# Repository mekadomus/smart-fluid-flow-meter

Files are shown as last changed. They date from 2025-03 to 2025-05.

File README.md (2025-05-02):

# Smart Fluid Flow Meter



Hardware and software for a system that monitors flow of fluids (most likely water) and reports it to a back-end that can emit alerts based on configured preferences.

- [case](/case/) - 3d model of the PCB case
- [firmware](/firmware/) - The firmware code that takes care of reading the sensor and posting measurements to the back-end
- [electronics](/electronics/) - Electronic circuit schematic and pcb

## User documentation

- [English](/docs/en/)
- [Español](/docs/es/)

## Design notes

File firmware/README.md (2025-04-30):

# ESP32

The firmware for `smart-fluid-flow-meter`.

Reads measurements from [YF-S201](http://www.mantech.co.za/datasheets/products/yf-s201_sea.pdf) and publishes them to the back-end.

## Configure

A few settings can be configured to modify the resulting executable. To set these configurations you need to create the configuration file:

```
cp sdkconfig.sample src/sdkconfig.defaults
```

And then update `src/sdkconfig.defaults` as desired

## Update git submodules

```
git submodule update --init --recursive
```

## Compile

To generate a docker image and build the code:

```
make build
```

## Upload to ESP32 dev board

Assumes the device is connected at `/dev/ttyACM0`.

```
make upload
```

## Monitor serial port

Assumes the device is connected at `/dev/ttyACM0`.

```
make serial
```

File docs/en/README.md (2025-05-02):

# User documentation

## LED indicators

- **Yellow** - Device is booting
- **Green, yellow and red** - Device set to factory settings and waiting for configuration (See below for instructions to configure)
- **Green** - Device is configured and behaving correctly
- **Green and yellow** - Device is in the middle of sending a request to the back-end
- **Red** - Last request to back-end failed. This could be because configuration is incorrect, or the configured modem is unreachable
- **None** - This should not happen, it means something is very wrong

## Configuration

When the device is in factory settings (Green, yellow and red LEDs on), the firmware will start an access point named `my-esp32-ssid`. Connect to the access point using the password `APassword`.

Once connected, navigate to the url: `sffm.mekadomus.com`. You should get a screen like the following:

Configure device screen

Fill the data as follows:
- *Wifi Network* - The name of the network the device will connect to
- *Wifi Password* - The password for the given SSID
- *Device key* - The unique identifier for this device. This ID must match the ID of a device created at the backend ([https://console.mekadomus.com](https://console.mekadomus.com))

After submitting the form, you should get the following confirmation screen:

Configuration saved screen

The device will proceed to disable the access point and will start reading measurements from the sensor and sending them to the backend every  `MS_BETWEEN_POSTS`.

## Factory reset

If you need to re-configure the device, press and hold the device button for 5 seconds. After some time the green, yellow and red LEDs should all turn on.

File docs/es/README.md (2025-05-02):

# User documentation

## Indicadores LED

- **Amarillo** - Dispositivo iniciando
- **Verde, amarillo y rojo** - Dispositivo en modo fábrica. Listo para ser configurado (Ver instrucciones abajo para configurar)
- **Verde** - Dispositivo configurado y funcionando correctamente
- **Verde y amarillo** - Dispositivo enviando información a servidores
- **Rojo** - La última petición a los servidores fallo. Esto puede suceder porque el dispositivo está mal configurado o el punto de acceso no está disponible
- **Ninguno** - Esto nunca debería suceder. Significa que algo está funcionando mal

## Configuración

Cuando el dispositivo está en modo fabrica (Indicadores LED verde, amarillo y rojo están encendidos), el dispositivo crea un punto de acceso llamado `my-esp32-ssid`. Conéctate a esa red usando la contraseña `APassword`.

Una vez conectado, visita la dirección `sffm.mekadomus.com`. Verás una página similar a la siguiente:

Configure device screen

Llena los datos:
- *Red* - El nombre de la red al que se conectará el dispositivo
- *Contraseña* - Contraseña de la red seleccionada
- *ID del medidor* - Identificador para este dispositivo. Debe ser igual a un ID creado desde el panel de control: ([https://console.mekadomus.com](https://console.mekadomus.com))

Después de enviar la información recibirás este mensaje:

Configuration saved screen

El dispositivo desactivará el punto de acceso `my-esp32-ssid` y empezará a mandar mediciones a los servidores cada `MS_BETWEEN_POSTS`.

## Modo fábrica

Si necesitar reconfigurar el dispositivo, mantén presionado el botón en el dispositivo por 5 segundos. Los LEDs verde, amarillo y rojo se encenderán de nuevo y el dispositivo estará listo para configurarse.

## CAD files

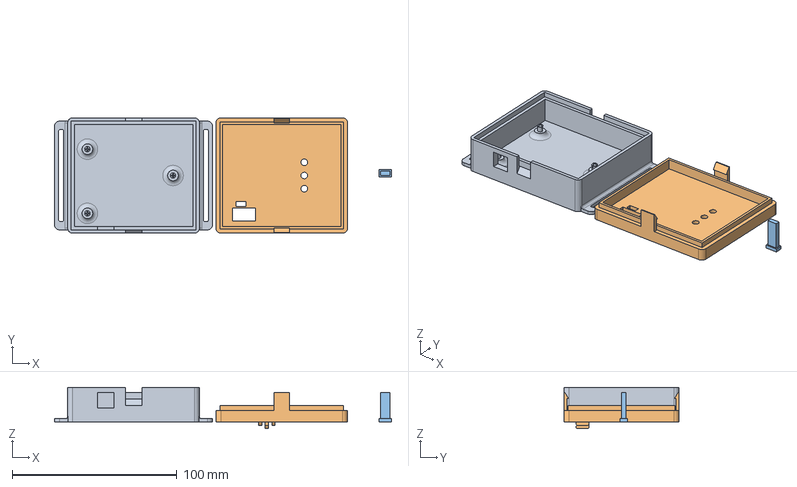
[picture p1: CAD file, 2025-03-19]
case/indoor/case.FCStd
204.7 x 70.0 x 25.0 mm
bottom_b
top_b
button_b

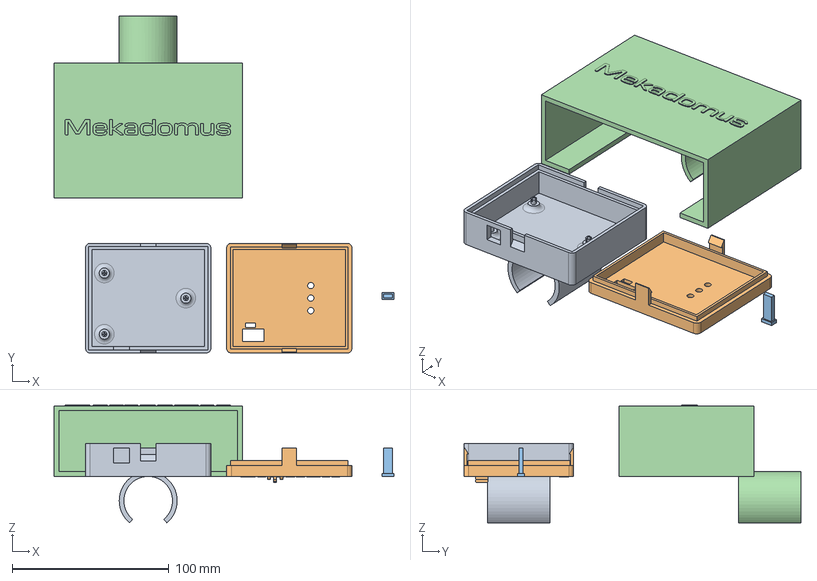
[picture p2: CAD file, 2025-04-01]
case/outdoor/case.FCStd
216.7 x 215.0 x 75.2 mm
bottom_b
top_b
button_b
rain_protector_body

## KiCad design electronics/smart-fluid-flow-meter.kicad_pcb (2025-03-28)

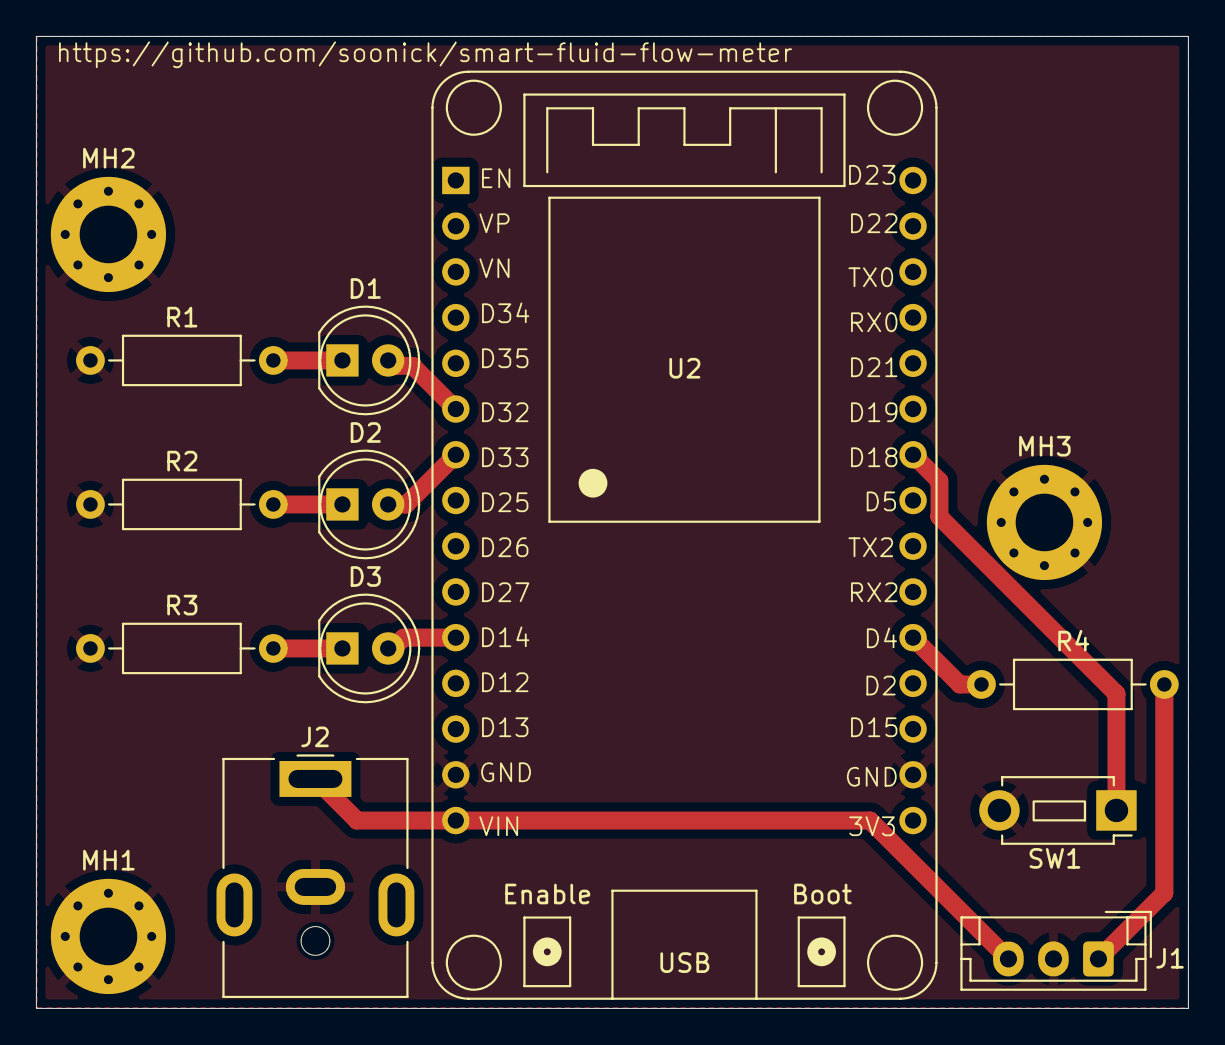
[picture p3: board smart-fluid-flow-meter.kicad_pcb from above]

Board: 2 copper layers, 64.0 x 54.0 mm, 14 parts (0 on the bottom side), 11 nets.

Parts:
D1: Green LED; LED_D5.0mm
D2: Yellow LED; LED_D5.0mm
D3: Red LED; LED_D5.0mm
J1: YF-S201; JST_EH_B3B-EH-A_1x03_P2.50mm_Vertical
J2: Barrel_Jack; BarrelJack_CUI_PJ-063AH_Horizontal
MH1, MH2, MH3: MountingHole_Pad; MountingHole_3.2mm_M3_Pad_Via
R1, R3: 220; R_Axial_DIN0207_L6.3mm_D2.5mm_P10.16mm_Horizontal
R2: 100; R_Axial_DIN0207_L6.3mm_D2.5mm_P10.16mm_Horizontal
R4: 3.3M; R_Axial_DIN0207_L6.3mm_D2.5mm_P10.16mm_Horizontal
SW1: Factory reset button; SW_PUSH_1P1T_6x3.5mm_H4.3_APEM_MJTP1243
U2: ESP32-DevkitV1; esp32_devkit_v1

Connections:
0: J1.2, J2.2, MH1.1, MH2.1, MH3.1, R1.1, R2.1, R3.1, SW1.2, U2.2 (GND), U2.29 (GND)
unnamed: D1.2 (A), U2.21 (D32)
unnamed: D1.1 (K), R1.2
unnamed: D2.2 (A), U2.22 (D33)
unnamed: D2.1 (K), R2.2
unnamed: D3.2 (A), U2.26 (D14)
unnamed: D3.1 (K), R3.2
unnamed: J1.1, R4.2
unnamed: J1.3, J2.1, U2.30 (VIN)
unnamed: R4.1, U2.5 (D4)
unnamed: SW1.1, U2.9 (D18)

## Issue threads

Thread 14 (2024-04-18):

Create network where user can input network credentials

soonick, 2024-04-18:

soonick, 2024-04-19:
Here is basically what we need: https://www.instructables.com/Avoid-Hard-Coding-WiFi-Credentials-on-Your-ESP8266/

soonick, 2024-04-19:
That library doesn't work with Arduino UNO R4 Wifi. This might be useful: https://www.elektroda.com/rtvforum/topic4000214.html

Closed 2024-06-26.

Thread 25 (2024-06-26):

Reset user configuration when a reset button is long pressed

soonick, 2024-06-26:

Closed 2024-07-05.

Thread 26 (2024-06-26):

Show in LEDs the current status of the system

soonick, 2024-06-26:
- AP is on
- Connected to configured network
- Configured but not connected
- Booting
- Resetting

soonick, 2024-07-23:
Connected to configured network: Green
AP mode: Yellow
Error connecting to network: Red
Booting/Resetting: Blinking all LEDs

Closed 2024-11-25.

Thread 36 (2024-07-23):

Wifi posts are super unreliable

soonick, 2024-07-23:

soonick, 2024-08-06:
Since we are moving to ESP32, this might change. I'll re-open if I find the same issue there

Closed 2024-08-06.

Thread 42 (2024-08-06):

[Arduino -> ESP32] Reset wifi credentials functionality

soonick, 2024-08-06:

Closed 2024-11-12.

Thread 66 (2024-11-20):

Investigate if there is a way to use low power mode and wake up from interrupt

soonick, 2024-11-20:

soonick, 2024-11-22:
Won't do as using battery doesn't seem to be an option for now

Closed 2024-11-22.

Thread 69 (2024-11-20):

Battery usage analysis

soonick, 2024-11-20:

soonick, 2024-11-20:
**Current measurements**

- Long sleep - 0.34 mA
- Wifi on. Sending https requests - 1.27 mA
- Access point on - 1.18 mA

My local supplier has these 3.7v LiPo batteries:

- 1000 mAh - 4 USD
- 2000 mAh - 8 USD

Which means, at maximum power consumption, the batteries would last approximately:

- 1000 mAh - 1 month
- 2000 mAh - 2 months

At minimum power consumption, the batteries would last approximately:

- 1000 mAh - 4 months
- 2000 mAh - 8 months

If I only use wifi every few hours, maybe I can get 6 moths for the large battery, but it still seems like too little autonomy. Deep sleep (if even possible) might add a nother couple of months, but 8 months still sounds like too little. I'll stick to a plugged solution for now.

soonick, 2024-11-20:
After some research, my previous measurements might be wrong. After checking the amp meter settings, I can see that with the wifi on and sending data, usage can get up to 160 mA.

This makes the autonomy even worse, so I'm just going to continue with a plugged solution.

Closed 2024-11-20.

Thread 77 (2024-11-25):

PCB improvements

soonick, 2024-11-25:
- Use wider traces
- GND plane / pour

After done, send PCB for review to https://www.reddit.com/r/PrintedCircuitBoard/ making sure to follow https://old.reddit.com/r/PrintedCircuitBoard/wiki/index#wiki_instructions_for_reviews

soonick, 2024-11-28:
Sent for review: https://www.reddit.com/r/PrintedCircuitBoard/comments/1h24an5/review_request_esp32devkitv1_with_water_flow/

Closed 2024-12-02.

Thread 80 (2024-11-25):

HTTPS requests sometimes fails

soonick, 2024-11-25:
It seems to be a recoverable error. This is a log:

```
E (21600716) smart-fluid-flow-meter: Sending request
I (21600756) wifi:wifi driver task: 3ffd4168, prio:23, stack:6656, core=0
I (21600766) wifi:wifi firmware version: ccaebfa
I (21600766) wifi:wifi certification version: v7.0
I (21600766) wifi:config NVS flash: enabled
I (21600776) wifi:config nano formating: disabled
I (21600776) wifi:Init data frame dynamic rx buffer num: 32
I (21600786) wifi:Init static rx mgmt buffer num: 5
I (21600786) wifi:Init management short buffer num: 32
I (21600786) wifi:Init dynamic tx buffer num: 32
I (21600796) wifi:Init static rx buffer size: 1600
I (21600796) wifi:Init static rx buffer num: 10
I (21600806) wifi:Init dynamic rx buffer num: 32
I (21600856) wifi_init: rx ba win: 6
I (21600856) wifi_init: accept mbox: 6
I (21600856) wifi_init: tcpip mbox: 32
I (21600856) wifi_init: udp mbox: 6
I (21600856) wifi_init: tcp mbox: 6
I (21600886) wifi_init: tcp tx win: 5760
I (21600886) wifi_init: tcp rx win: 5760
I (21600886) wifi_init: tcp mss: 1440
I (21600886) wifi_init: WiFi IRAM OP enabled
I (21600886) wifi_init: WiFi RX IRAM OP enabled
I (21600956) wifi:mode : sta (a0:dd:6c:0e:ef:80)
I (21600956) wifi:enable tsf
I (21600966) backend-service: Connecting to Chacmultun-13-2...
W (21600966) wifi:Password length matches WPA2 standards, authmode threshold changes from OPEN to WPA2
W (21600986) event: handler already registered, overwriting
I (21600996) wifi:new:<11,2>, old:<1,0>, ap:<255,255>, sta:<11,2>, prof:1, snd_ch_cfg:0x0
I (21600996) wifi:state: init -> auth (0xb0)
I (21601006) wifi:state: auth -> assoc (0x0)
I (21601016) wifi:state: assoc -> run (0x10)
I (21601036) wifi:connected with Chacmultun-13-2, aid = 3, channel 11, 40D, bssid = 14:cc:20:fd:13:d5
I (21601036) wifi:security: WPA2-PSK, phy: bgn, rssi: -72
I (21601036) wifi:pm start, type: 1

I (21601036) wifi:dp: 1, bi: 102400, li: 3, scale listen interval from 307200 us to 307200 us
I (21601096) wifi:AP's beacon interval = 102400 us, DTIM period = 1
I (21603146) wifi:<ba-add>idx:0 (ifx:0, 14:cc:20:fd:13:d5), tid:0, ssn:0, winSize:64
I (21604046) backend-service: Got IP address
I (21604046) esp_netif_handlers: sta ip: 192.168.1.198, mask: 255.255.255.0, gw: 192.168.1.254
I (21604796) esp-x509-crt-bundle: Certificate validated
I (21606106) backend-service: HTTP_EVENT_ON_CONNECTED
I (21606116) backend-service: HTTP_EVENT_HEADER_SENT
W (21611166) HTTP_CLIENT: Connection timed out before data was ready!
E (21611166) backend-service: Error with https request: ESP_ERR_HTTP_EAGAIN
I (21611166) backend-service: HTTP_EVENT_DISCONNECTED
I (21611226) backend-service: Turning off wifi
I (21611226) wifi:state: run -> init (0x0)
I (21611236) wifi:pm stop, total sleep time: 8248384 us / 10194646 us

I (21611236) wifi:<ba-del>idx:0, tid:0
I (21611236) wifi:new:<11,0>, old:<11,2>, ap:<255,255>, sta:<11,2>, prof:1, snd_ch_cfg:0x0
E (21611246) wifi:NAN WiFi stop
I (21611306) wifi:flush txq
I (21611306) wifi:stop sw txq
I (21611306) wifi:lmac stop hw txq
I (21611686) wifi:Deinit lldesc rx mblock:10
```

A link with some information: https://www.reddit.com/r/embedded/comments/1bo9rwh/connection_sometimes_times_out_in_esp32c3/

Closed 2024-11-25.

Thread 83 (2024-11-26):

ESP32 sometimes gets stuck in the middle of a request

soonick, 2024-11-26:
The green and yellow LEDs remain on and we this is the last thing in the logs:

```
E (7214246) smart-fluid-flow-meter: Request failed
I (7214286) wifi:wifi driver task: 3ffcb398, prio:23, stack:6656, core=0
I (7214296) wifi:wifi firmware version: ccaebfa
I (7214296) wifi:wifi certification version: v7.0
I (7214296) wifi:config NVS flash: enabled
I (7214296) wifi:config nano formating: disabled
I (7214306) wifi:Init data frame dynamic rx buffer num: 32
I (7214306) wifi:Init static rx mgmt buffer num: 5
I (7214316) wifi:Init management short buffer num: 32
I (7214316) wifi:Init dynamic tx buffer num: 32
I (7214326) wifi:Init static rx buffer size: 1600
I (7214326) wifi:Init static rx buffer num: 10
I (7214336) wifi:Init dynamic rx buffer num: 32
I (7214376) wifi_init: rx ba win: 6
I (7214376) wifi_init: accept mbox: 6
I (7214376) wifi_init: tcpip mbox: 32
I (7214376) wifi_init: udp mbox: 6
I (7214376) wifi_init: tcp mbox: 6
I (7214406) wifi_init: tcp tx win: 5760
I (7214406) wifi_init: tcp rx win: 5760
I (7214406) wifi_init: tcp mss: 1440
I (7214406) wifi_init: WiFi IRAM OP enabled
I (7214406) wifi_init: WiFi RX IRAM OP enabled
I (7214476) wifi:mode : sta (a0:dd:6c:0e:ef:80)
I (7214476) wifi:enable tsf
I (7214486) backend-service: Connecting to Chacmultun-13-2...
W (7214486) wifi:Password length matches WPA2 standards, authmode threshold changes from OPEN to WPA2
W (7214516) event: handler already registered, overwriting
I (7214556) wifi:new:<11,2>, old:<1,0>, ap:<255,255>, sta:<11,2>, prof:1, snd_ch_cfg:0x0
I (7214556) wifi:state: init -> auth (0xb0)
I (7214576) wifi:state: auth -> assoc (0x0)
I (7215576) wifi:state: assoc -> init (0x2700)
I (7215586) wifi:new:<11,0>, old:<11,2>, ap:<255,255>, sta:<11,2>, prof:1, snd_ch_cfg:0x0
```

soonick, 2024-11-26:
This happened when I left the device connected to my computer with the idf monitor on. I wonder if it might be caused by my computer going to sleep.

soonick, 2024-11-26:
It happened when I left the device connected to my computer without idf monitor, so the problem is not the monitor

soonick, 2024-11-27:
I have left the device connected for more than 24 hours, and it seems to be working fine. I suspect it might have something to do with the computer I was plugging it to going to sleep mode.

Closing this issue. I'll reopen if I notice it happens again.

Closed 2024-11-27.

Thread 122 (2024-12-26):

Make esp32 holes larger on PCB design

soonick, 2024-12-26:
The pins of the esp32 dev board are too thick compared to the holes for them, so it's very hard to insert the board in the PCB

Closed 2025-01-03.

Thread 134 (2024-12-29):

Firmware gets stuck on yellow LED

soonick, 2024-12-29:
It has happened a few times that the firmware gets stuck on the yellow LED. Need to figure out the reason and fix it

Closed 2024-12-31.

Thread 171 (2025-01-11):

Password reset flow

soonick, 2025-01-11:

Closed 2025-02-27.

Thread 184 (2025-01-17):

SameSite attribute for authorization cookie

soonick, 2025-01-17:
I'm getting this browser error:

Cookie “authorization” does not have a proper “SameSite” attribute value. Soon, cookies without the “SameSite” attribute or with an invalid value will be treated as “Lax”. This means that the cookie will no longer be sent in third-party contexts. If your application depends on this cookie being available in such contexts, please add the “SameSite=None“ attribute to it. To know more about the “SameSite“ attribute, read https://developer.mozilla.org/docs/Web/HTTP/Headers/Set-Cookie/SameSite

soonick, 2025-02-12:
Can't reproduce anymore

Closed 2025-02-12.

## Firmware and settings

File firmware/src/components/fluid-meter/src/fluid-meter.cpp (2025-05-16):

#include "fluid-meter.hpp"

#include <driver/gpio.h>
#include <esp_log.h>

int FluidMeter::total_pulses = 0;
FluidMeter* FluidMeter::instance = nullptr;
QueueHandle_t FluidMeter::queue;
// The conversion factor varies depending on the sensor being used
#if CONFIG_SENSOR_YF_S201
float FluidMeter::conversion_factor = 690;
#elif CONFIG_SENSOR_FS400A
// TODO: Update this value after experimenting
float FlFluidMeter::conversion_factor = 1;
#endif

FluidMeter::FluidMeter(const gpio_num_t pin) : meter_pin{pin} {
  queue = xQueueCreate(10, sizeof(char));
  xTaskCreate(queue_task, "queue_task", 2048, NULL, 10, NULL);

  gpio_config_t interrupt_config = {
      .pin_bit_mask = 1ULL << meter_pin,
      .mode = GPIO_MODE_INPUT,
      .pull_up_en = GPIO_PULLUP_DISABLE,
      .pull_down_en = GPIO_PULLDOWN_DISABLE,
      .intr_type = GPIO_INTR_POSEDGE,
  };
  gpio_config(&interrupt_config);

  gpio_install_isr_service(0);
  gpio_isr_handler_add(meter_pin, this->count_pulses, nullptr);
}

FluidMeter* FluidMeter::get_instance(const gpio_num_t pin) {
  if (FluidMeter::instance == nullptr) {
    FluidMeter::instance = new FluidMeter(pin);
  }

  return FluidMeter::instance;
}

void FluidMeter::queue_task(void* params) {
  char c;
  while (true) {
    if (xQueueReceive(queue, &c, portMAX_DELAY)) {
      FluidMeter::total_pulses++;
    }
  }
}

void FluidMeter::count_pulses(void* args) {
  char c = 1;
  xQueueSendFromISR(queue, &c, nullptr);
}

float FluidMeter::get_volume() {
  int pulses;

  // Protect total_pulses by disabling interrupts
  portDISABLE_INTERRUPTS();
  pulses = this->total_pulses;
  this->total_pulses = 0;
  portENABLE_INTERRUPTS();

  return pulses / conversion_factor;
}

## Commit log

2025-01-05 [esp32] Use configuration for backend url. #153 (#158)
2025-01-16 [frontend] Log in flow. #107 (#178)
2025-01-26 [backend] Endpoint for creating new devices. #186 (#190)
2025-01-27 [frontend] Create new device. Fixes #186 (#193)
2025-01-27 [frontend] Show list of devices in dashboard. Fixes #109 (#194)
2025-02-11 Switch from firestore to PostgreSQL (#197)
2025-02-12 [backend] Reject measurement requests for not-existing or not-active devices. Fixes #111 (#206)
2025-02-13 [backend] Limit the number of requests we accept from a device. Fixes #113 (#207)
2025-02-16 Make it possible to switch to JSON logging via configuration. Fixes #216 (#217)
2025-03-14 [backend] Allow to filter meters by status. #202 (#227)
2025-03-19 [case] Add clips for holding PCB to case. Fixes #128 (#233)
    [case.FCStd]
2025-03-19 [case] Add clip for holding water sensor cable. Fixes #160 (#234)
    [case.FCStd]
2025-03-19 [case] Add a way to attach case to water pipe. Fixes #100 (#235)
    [case.FCStd]
2025-03-20 [frontend] Button to activate / deactivate meter. Fixes #237 (#242)
2025-03-25 [backend] Send alerts digest instead of one alert per device. #239 (#245)
2025-03-28 [electronics][firmware] Rename esp32 and kicad folders to firmware and electronics (#255)
    [smart-fluid-flow-meter.kicad_pcb, smart-fluid-flow-meter.kicad_sch]
2025-03-28 [case] Add brand to outside case. #101 (#256)
    [case.FCStd]
2025-04-01 [case] Rain protector. Fixes #101 (#257)
    [case.FCStd]
2025-04-30 Mention in the documentation that the device id needs to be created in the console. Fix #265 (#266)
2025-05-16 Add sensor model configuration. #126 (#270)
